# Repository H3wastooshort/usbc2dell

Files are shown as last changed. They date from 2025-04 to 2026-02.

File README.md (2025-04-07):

# USB-C to DELL
An adapter to allow charging Laptops equipped with legacy connectors via USB Type-C.

a rendered animation of the PCB roatating

## Why make my own?

I could just slap together a USB-C PD trigger-board and a cut-off end of a cable and call it a day, but that would cause two problems:
 - the laptop won't charge because it's not seeing an ID chip
 - even if it does use the power supply, it might draw too much current if connected to for example a 45W USB-C power supply.

This project remidies this, by negotiating USB PD and then emulating an ID chip with the same parameters as read from the USB-C power supply. Using a 45W USB-C power supply, the laptop will know that it's only capable of 45W.

## Schematic
the schematic

## PCB
a rendered image of the PCB front
a rendered image of the PCB back

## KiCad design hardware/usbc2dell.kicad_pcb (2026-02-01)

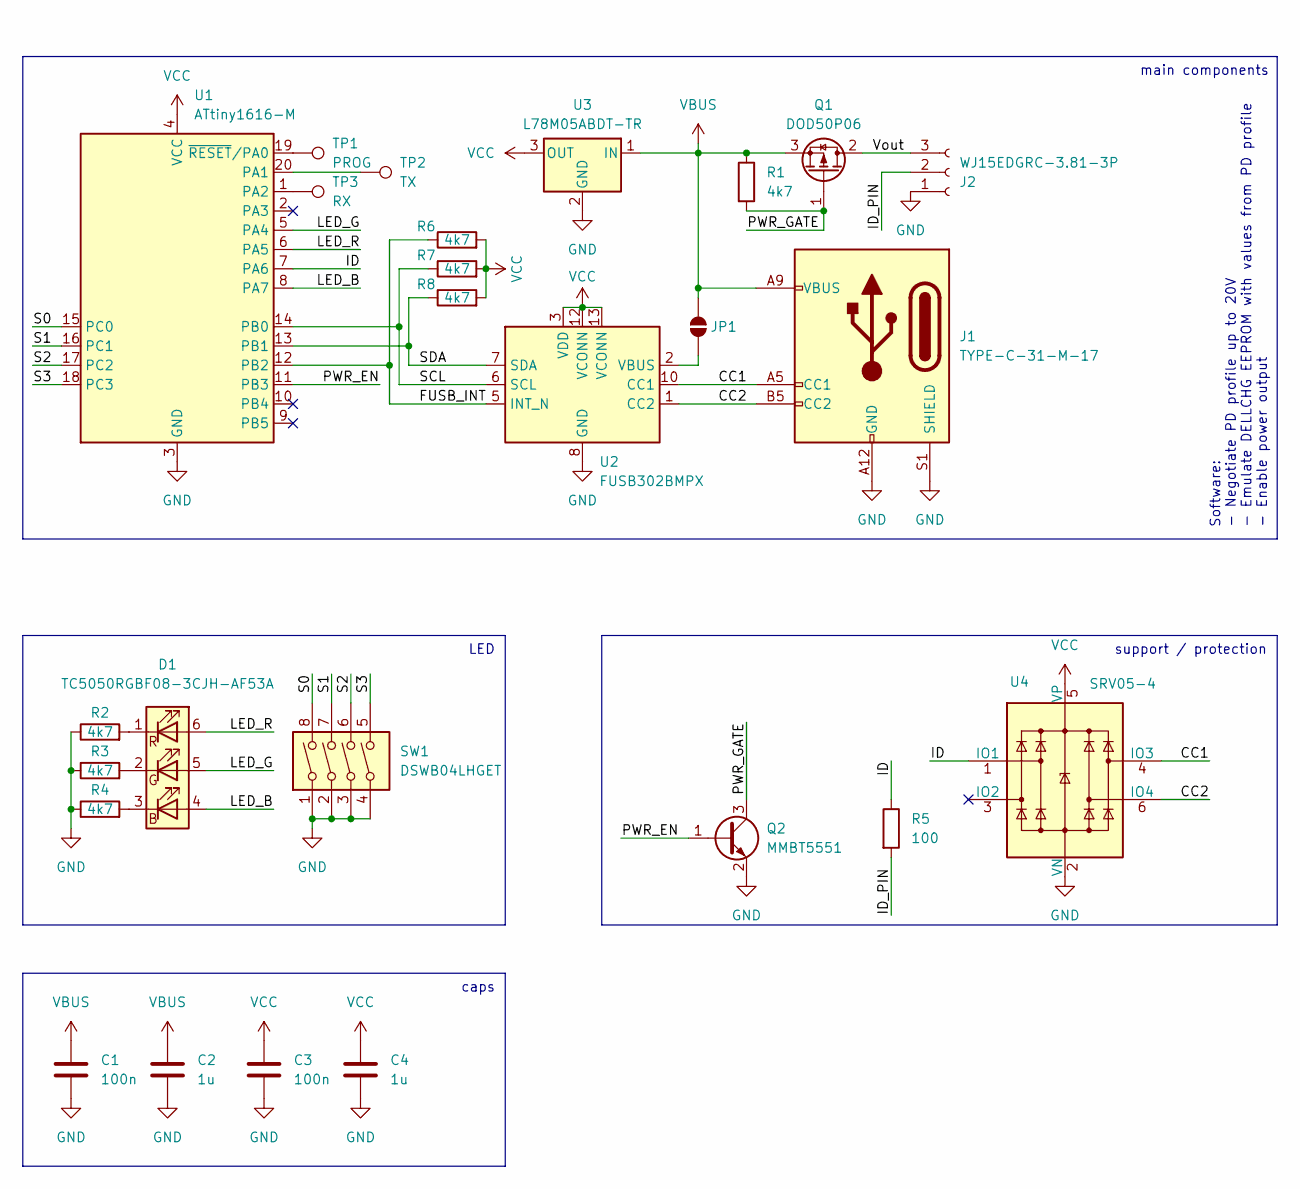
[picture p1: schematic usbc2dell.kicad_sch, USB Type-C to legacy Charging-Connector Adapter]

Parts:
C1, C3: 100n; C_0603_1608Metric; LCSC C14663
C2, C4: 1u; C_0603_1608Metric; LCSC C15849
D1: TC5050RGBF08-3CJH-AF53A; LED_RGB_5050-6; LCSC C784540
J1: TYPE-C-31-M-17; USB_C_Receptacle_HRO_TYPE-C-31-M-17; LCSC C283540
J2: WJ15EDGRC-3.81-3P; PhoenixContact_MC_1,5_3-G-3.81_1x03_P3.81mm_Horizontal; LCSC C8406
JP1: SolderJumper_2_Open; SolderJumper-2_P1.3mm_Open_TrianglePad1.0x1.5mm
Q1: DOD50P06; TO-252-3_TabPin2; LCSC C41430590
Q2: MMBT5551; SOT-23; LCSC C2145
R1, R2, R3, R4, R6, R7, R8: 4k7; R_0603_1608Metric; LCSC C23162
R5: 100; R_0603_1608Metric; LCSC C22775
SW1: DSWB04LHGET; SW_DIP_SPSTx04_Slide_9.78x12.34mm_W7.62mm_P2.54mm; LCSC C99418
TP1: PROG; TestPoint_Pad_D2.0mm
TP2: TX; TestPoint_Pad_D2.0mm
TP3: RX; TestPoint_Pad_D2.0mm
U1: ATtiny1616-M; VQFN-20-1EP_3x3mm_P0.4mm_EP1.7x1.7mm
U2: FUSB302BMPX; WQFN-14-1EP_2.5x2.5mm_P0.5mm_EP1.45x1.45mm; LCSC C442699
U3: L78M05ABDT-TR; TO-252-3_TabPin2; LCSC C58069
U4: SRV05-4; SOT-23-6; LCSC C20615829

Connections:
/CC1: J1.A5 (CC1), U2.10 (CC1), U2.11 (CC1), U4.4 (IO3)
/CC2: J1.B5 (CC2), U2.1 (CC2), U2.14 (CC2), U4.6 (IO4)
/FUSB_INT: R6.1, U1.12 (PB2), U2.5 (INT_N)
/ID: R5.1, U1.7 (PA6), U4.1 (IO1)
/ID_PIN: J2.2, R5.2
/LED_B: D1.4 (BA), U1.8 (PA7)
/LED_G: D1.5 (GA), U1.5 (PA4)
/LED_R: D1.6 (RA), U1.6 (PA5)
/PWR_EN: Q2.1 (B), U1.11 (PB3)
/PWR_GATE: Q1.1 (G), Q2.3 (C), R1.2
/S0: SW1.8, U1.15 (PC0)
/S1: SW1.7, U1.16 (PC1)
/S2: SW1.6, U1.17 (PC2)
/S3: SW1.5, U1.18 (PC3)
/SCL: R7.1, U1.14 (PB0), U2.6 (SCL)
/SDA: R8.1, U1.13 (PB1), U2.7 (SDA)
/Vout: J2.3, Q1.2 (D)
GND: C1.2, C2.2, C3.2, C4.2, J1.A12 (GND), J1.B12 (GND), J1.S1 (SHIELD), J2.1, Q2.2 (E), R2.1, R3.1, R4.1, SW1.1, SW1.2, SW1.3, SW1.4, U1.3 (GND), U1.21 (GND), U2.8 (GND), U2.9 (GND), U2.15 (GND), U3.2 (GND), U4.2 (VN)
unnamed: D1.3 (BK), R4.2
unnamed: D1.2 (GK), R3.2
unnamed: D1.1 (RK), R2.2
unnamed: JP1.1 (A), U2.2 (VBUS)
unnamed: TP2.1, U1.20 (PA1)
unnamed: TP3.1, U1.1 (PA2)
unnamed: TP1.1, U1.19 (~RESET/PA0)
VBUS: C1.1, C2.1, J1.A9 (VBUS), J1.B9 (VBUS), JP1.2 (B), Q1.3 (S), R1.1, U3.1 (IN)
VCC: C3.1, C4.1, R6.2, R7.2, R8.2, U1.4 (VCC), U2.3 (VDD), U2.4 (VDD), U2.12 (VCONN), U2.13 (VCONN), U3.3 (OUT), U4.5 (VP)

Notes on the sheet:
caps
Software: - Negotiate PD profile up to 20V - Emulate DELLCHG EEPROM with values from PD profile - Enable power output
LED
support / protection
main components

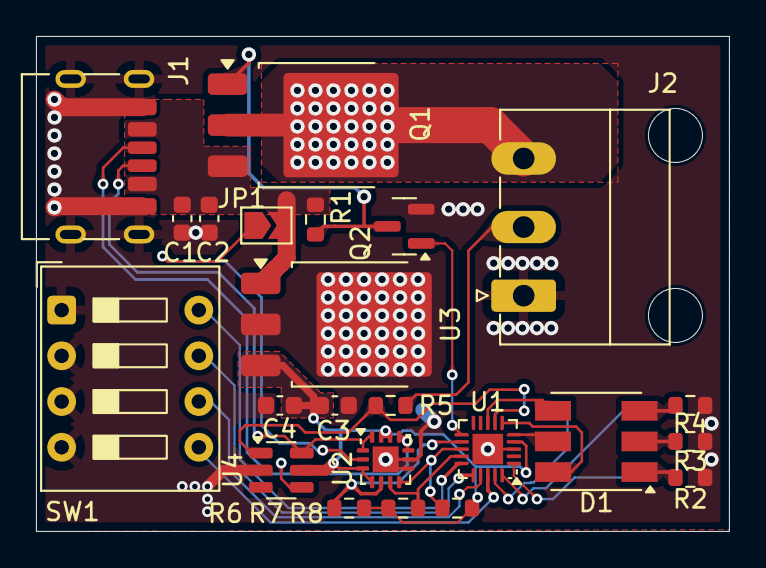
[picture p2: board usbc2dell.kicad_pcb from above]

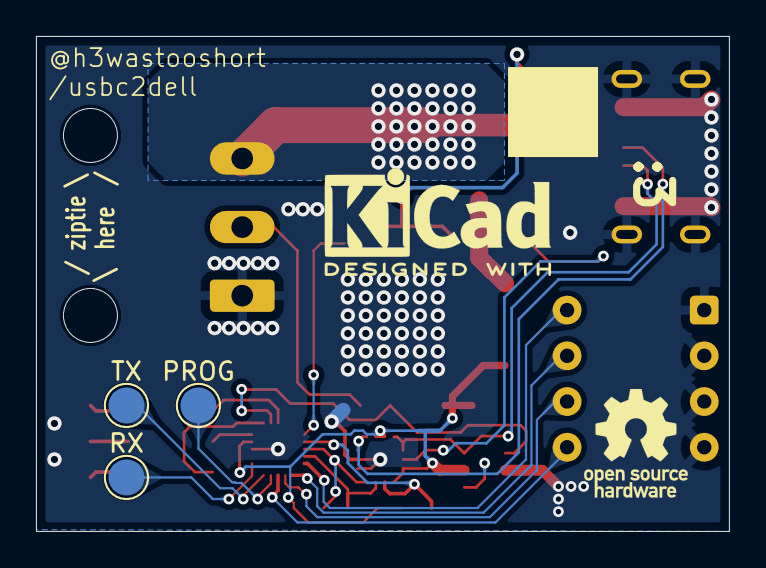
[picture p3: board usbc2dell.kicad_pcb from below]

Board: 2 copper layers, 38.5 x 27.5 mm, 30 parts (5 on the bottom side), 27 nets.

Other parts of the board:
HOLE1, HOLE2: MountingHole_3mm
ICON1: OSHW-Logo_5.7x6mm_SilkScreen
ICON2: KiCad-Logo2_5mm_SilkScreen

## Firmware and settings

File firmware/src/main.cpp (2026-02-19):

#include <Arduino.h>
#include <Wire.h>
#include "pins.hpp"
#include "chg_emu_dell.hpp"
#include "led.hpp"
#include "power.hpp"
#include "emu_controller.hpp"
#include "debug.hpp"

EmuController* ec = NULL;

void setup()
{
    set_power(false);
    // TODO: init pins
    pinMode(PIN_SW_EMU_TYPE_0, INPUT_PULLUP);
    pinMode(PIN_SW_EMU_TYPE_1, INPUT_PULLUP);
    pinMode(PIN_SW_USE_PPS, INPUT_PULLUP);
    pinMode(PIN_SW_LED_BRIGHT, INPUT_PULLUP);
    //init LED
    for (uint8_t i = 0; i<3; i++) {digitalWrite(PINS_LED[i], LOW); pinMode(PINS_LED[i], OUTPUT);}
    set_led_color(LED_COLOR_BOOT);

    Logger::setup();

    //init appropriate emu

    uint8_t emu_mode = ( (digitalRead(PIN_SW_EMU_TYPE_0) << 1) | (digitalRead(PIN_SW_EMU_TYPE_0) << 0) ) & 0b11;
    bool use_pps = digitalRead(PIN_SW_USE_PPS);
    
    chg_emu_c* selected_emu = NULL;
    switch (emu_mode) {
        case 0b01:
        //TODO: HP emulator
        case 0b11:
        default:
            selected_emu = new chg_emu_dell_c(PIN_ID);
            break;
    }

    //Init Emu
    ec = new EmuController(&Wire,use_pps,selected_emu);
    ec->setup();
}

void loop()
{
    ec->loop();
}

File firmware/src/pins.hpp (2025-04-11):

#pragma once
#include <Arduino.h>

const uint8_t PIN_ID = PIN_PB4;

const uint8_t PIN_FUSB_INT = PIN_PB2;

const uint8_t PIN_PWR_EN = PIN_PB3;

//LED
const uint8_t PIN_LED_R = PIN_PA5;
const uint8_t PIN_LED_G = PIN_PA6;
const uint8_t PIN_LED_B = PIN_PA7;

//DIP Switchesa
const uint8_t PIN_SW_EMU_TYPE_0 = PIN_PC0;
const uint8_t PIN_SW_EMU_TYPE_1 = PIN_PC1;
const uint8_t PIN_SW_USE_PPS = PIN_PC2;
const uint8_t PIN_SW_LED_BRIGHT = PIN_PC3;



//automatic, ignore
constexpr uint8_t PINS_LED[3] = {PIN_LED_R,PIN_LED_G,PIN_LED_B};

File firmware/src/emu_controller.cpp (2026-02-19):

#include "emu_controller.hpp"
#include <PD_UFP.h>
#include "chg_emu.hpp"
#include "power.hpp"
#include "led.hpp"
#include "debug.hpp"

EmuController::EmuController(TwoWire* i2c, const bool use_pps, chg_emu_c *emulator) : i2c(i2c), use_pps(use_pps), emulator(emulator), negotiantion_state(NEG_INIT) {};

void EmuController::sm_change_state(const negotiantion_states_e new_state) {
    this->negotiantion_state=new_state;
    Logger::log(new_state);
}

void EmuController::sm_run() {
    switch (this->negotiantion_state) {
        default:
        case NEG_INIT:
            sm_change_state(NEG_WAIT_FOR_PD_TRANS);
            break;

        case NEG_WAIT_FOR_PD_TRANS:
            this->emulator->disable();
            set_power(false);
            set_led_color(LED_COLOR_NONE);
            sm_change_state(NEG_WAIT_FOR_PD);
            break;

        case NEG_WAIT_FOR_PD:
            if (pd.is_PPS_ready())
                sm_change_state(NEG_GOT_PPS_TRANS);
            else if (pd.is_power_ready())
                sm_change_state(NEG_GOT_20V_TRANS);
            break;

        case NEG_GOT_20V_TRANS:
            set_led_color(LED_COLOR_20V);
            this->emulator->set_param(pd.get_voltage() * 50 /*mV*/, pd.get_current() * 10 /*mA*/);
            this->emulator->enable();
            set_power(true);
            sm_change_state(NEG_GOT_20V);
            break;
        case NEG_GOT_20V: if (!pd.is_power_ready()) sm_change_state(NEG_WAIT_FOR_PD_TRANS);

        case NEG_GOT_PPS_TRANS:
            set_led_color(LED_COLOR_PPS);
            this->emulator->set_param(pd.get_voltage() * 20 /*mV*/, pd.get_current() * 50 /*mA*/);
            this->emulator->enable();
            set_power(true);
            sm_change_state(NEG_GOT_PPS);
            break;
        case NEG_GOT_PPS: if (!pd.is_PPS_ready()) sm_change_state(NEG_WAIT_FOR_PD_TRANS);
    }
}

void EmuController::setup() {
    this->emulator->setup();
    //this->i2c->swap(0);
    this->i2c->usePullups();
    this->i2c->setClock(10000);
    this->i2c->begin();
    this->i2c->usePullups();

    this->i2c->beginTransmission (0x22);
    if (this->i2c->endTransmission () != 0) while (1) { //blink if missing fusb
        set_led_color(LED_COLOR_BOOT);
        delay(500);
        set_led_color(LED_COLOR_ERR);
        delay(500);
    }

    if (use_pps)
        pd.init_PPS(PIN_FUSB_INT, PPS_V(19.5), PPS_A(5), PD_POWER_OPTION_MAX_20V);
    else
        pd.init(PIN_FUSB_INT, PD_POWER_OPTION_MAX_20V);
}

void EmuController::loop() {
    pd.run();
    this->sm_run();
    this->emulator->loop();
}

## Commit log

2025-04-01 rough schematic
    [usbc2dell.kicad_pcb, usbc2dell.kicad_sch]
2025-04-01 add config switchbank
    [usbc2dell.kicad_sch]
2025-04-03 add bjt to drive mosfet
    [usbc2dell.kicad_sch]
2025-04-04 try to fix upcast
    [main.cpp]
2025-04-04 rough PCB layout
    [usbc2dell.kicad_pcb, usbc2dell.kicad_sch]
2025-04-04 slightly miserable trace routing
    [usbc2dell.kicad_pcb, usbc2dell.kicad_sch]
2025-04-05 add ziptie-holes
    [usbc2dell.kicad_pcb]
2025-04-05 move hw files
    [usbc2dell.kicad_pcb, usbc2dell.kicad_sch]
2025-04-05 update action to kicad9
2025-04-05 added sort-of correct 3d models instead of none at all
    [usbc2dell.kicad_pcb]
2025-04-05 improve silkscreen
    [usbc2dell.kicad_pcb]
2025-04-06 add caps
    [usbc2dell.kicad_pcb, usbc2dell.kicad_sch]
2025-04-06 use pullup-resistors as transistor resistor
2025-04-06 more GND vias
    [usbc2dell.kicad_pcb]
2025-04-07 parts sel
    [usbc2dell.kicad_pcb, usbc2dell.kicad_sch]
2025-04-07 change ESD diodes
    [usbc2dell.kicad_pcb, usbc2dell.kicad_sch]
2025-04-07 move PCB
    [usbc2dell.kicad_pcb]
2025-04-07 add teardrops
    [usbc2dell.kicad_pcb]
2025-04-07 switch to phoenix-style connectors
    [usbc2dell.kicad_pcb, usbc2dell.kicad_sch]
2025-04-08 fix MOSFET
    [usbc2dell.kicad_pcb, usbc2dell.kicad_sch]
2025-04-08 fix mosfet 2
    [usbc2dell.kicad_pcb]
2025-04-10 forgot to commit, now don't remember what i did
    [usbc2dell.kicad_pcb]
2025-04-10 nicer traces + mosfet still fucked
    [usbc2dell.kicad_pcb, usbc2dell.kicad_sch]
2025-04-10 attempt to fix mosfet
    [usbc2dell.kicad_pcb, usbc2dell.kicad_sch]
2025-04-10 actually fix mosfet
    [usbc2dell.kicad_pcb]
2025-04-11 ledcolors 2
2025-04-11 LED dimming
2025-04-11 correct 7805 part num
    [usbc2dell.kicad_pcb, usbc2dell.kicad_sch]
2025-04-11 layout changes, thermals + ampacity
    [usbc2dell.kicad_pcb]
2025-04-11 comp sel
    [usbc2dell.kicad_pcb, usbc2dell.kicad_sch]
2025-05-08 put ID pin on pin with DAC capability for possible analog comms in future
    [usbc2dell.kicad_pcb, usbc2dell.kicad_sch]
2026-01-24 [FW] fix emulator selection
    [main.cpp]
2026-01-24 [FW] use correct type for emuselect
    [main.cpp]
2026-02-01 [PCB] fix pullups
    [usbc2dell.kicad_pcb, usbc2dell.kicad_sch]
2026-02-01 [PCB] move stuff
    [usbc2dell.kicad_pcb]
2026-02-01 [PCB] at JLCPCB serialnumber QR code position
    [usbc2dell.kicad_pcb]
2026-02-01 [PCB] idk
    [usbc2dell.kicad_pcb]
